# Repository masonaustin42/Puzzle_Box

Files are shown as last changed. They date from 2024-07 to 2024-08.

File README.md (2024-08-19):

# Puzzle Box

This puzzle box was created for my brother's bachelor party. The box displays a basic map on the LEDs on top, using a Teensy 4.1 microcontroller and an Arduino-compatible GPS receiver. 
The map updates in real-time, and helped navigate to different challenges that my brother had to complete to earn the codes to each of the different locks on the side of the box. The box cannot open until all 8 locks have been removed.
This project took about a month to develop, and it was made entirely from scratch aside from using some Arduino libraries to control the LEDs and interface with the GPS unit.

## Materials Used
- [Teensy 4.1](https://www.pjrc.com/store/teensy41.html)
- [NEO-6M GPS Receiver](https://a.co/d/7m8FWfx)
- [WS2812B Individually Addressable LED Rings](https://a.co/d/0RZDFQk)
- 4x [Brinks Luggage Padlock (2-Pack)](https://www.walmart.com/ip/Brinks-1-4in-32mm-3-Dial-Resettable-TSA-Luggage-Padlock-with-a-Steel-Cable-Shackle-2-Pack/5020233202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)
- All of the 3D Printed parts were in [Bambu Labs PLA Matte](https://us.store.bambulab.com/collections/bambu-lab-3d-printer-filament/products/pla-matte-filament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)

## Video Demo

https://github.com/user-attachments/assets/07382008-efad-4c62-b222-95e3310d10c2

## Example Usage

1. First, the device is powered on. Since the power switch is on the inside, this needs to be done before the locks are reinstalled.

2. Eight locks are installed on the exterior of the box, keeping it closed.

3. The GPS unit will look for a GPS signal. While the GPS is searching, the LEDs display a sweeping animation.

4. The map will update with the GPS data, showing the user's location in the center and a single point for the first objective the user must navigate to. For example, if the user was located in Seattle, WA and the first point was in San Francisco, CA the map would show the next point at the bottom of the display, indicating that the user needs to travel south.

5. The user then navigates to the point using the map. The map will continue to update as the user's location changes, displaying the relative location of the current objective, and getting closer to the center as the user approaches the destination.

6. Once the user successfully navigates to the objective, the LEDs will display a pulsing animation indicating that the user has arrived. This animation will last 3 minutes before updating again. This gives the user time to complete a task to find a code for a lock.

7. The display will then show the next objective. The user must repeat steps 4-6 for each objective.

8. Once the last objective is reached, a final rainbow animation will play indefinitely, indicating there are no more objectives to find. The locks may be removed from the puzzle box and the device can be shut down.

## Features

- Live location updates
- Custom animations
- Customizable amount of locations
- Battery Powered

## Technology Used

 





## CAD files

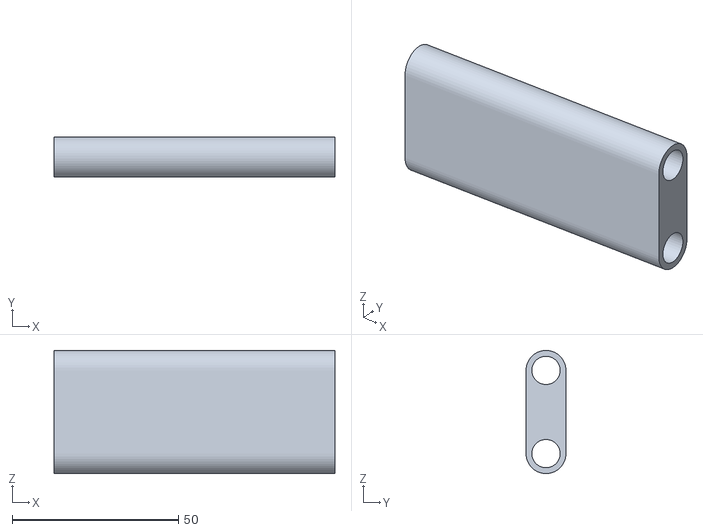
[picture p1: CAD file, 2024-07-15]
STLs/puzzle_box_hinge.stl
84.4 x 12.0 x 37.0

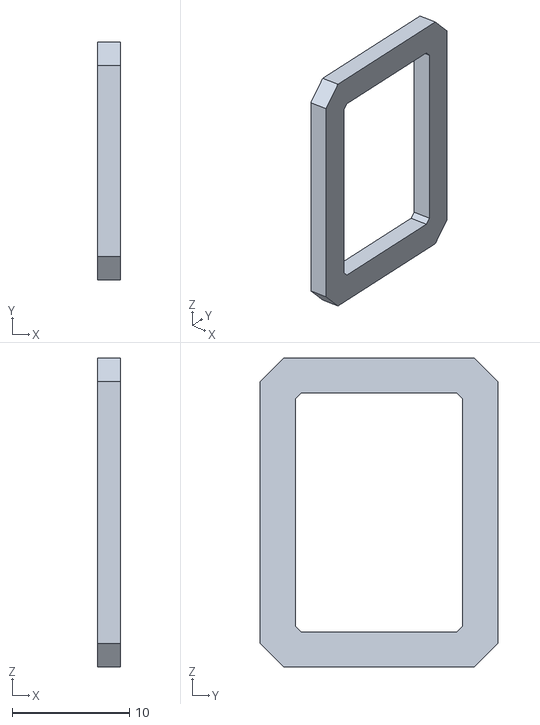
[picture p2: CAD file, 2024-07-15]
STLs/puzzle_box_clip.stl
2.00 x 20.3 x 26.4

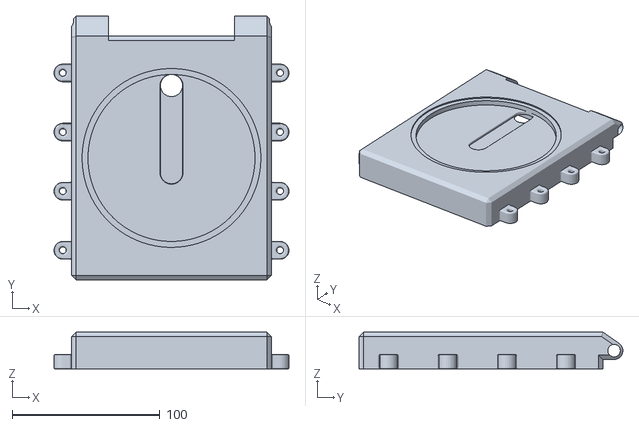
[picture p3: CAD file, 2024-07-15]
STLs/puzzle_box_lid.stl
159.0 x 178.5 x 24.8

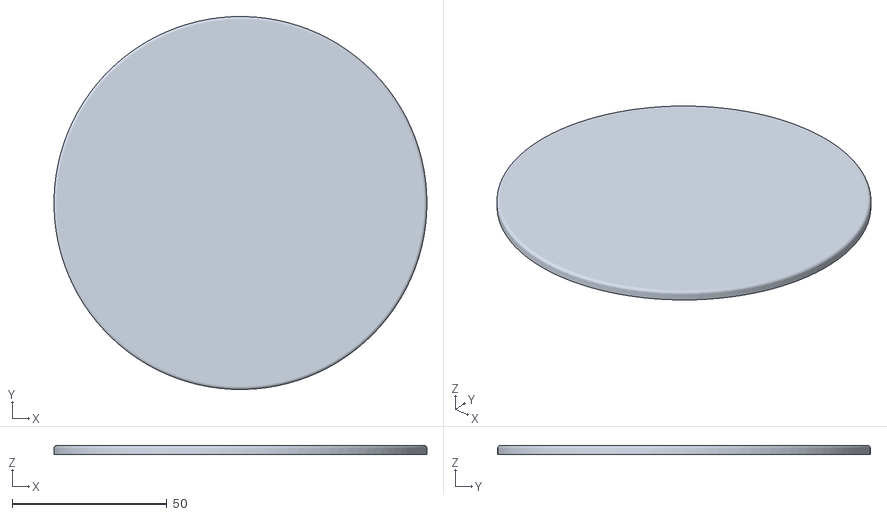
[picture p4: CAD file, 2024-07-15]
STLs/puzzle_box_diffuser.stl
120.6 x 120.6 x 3.00

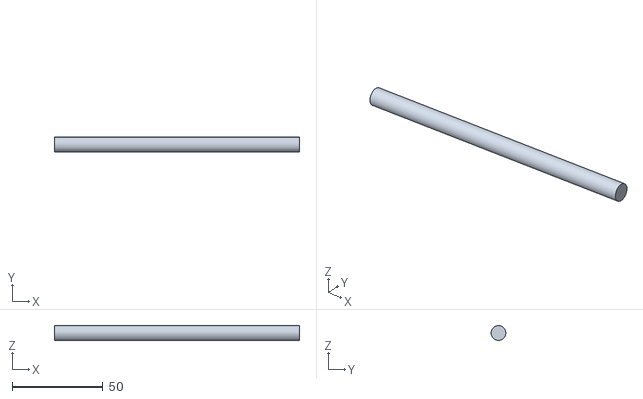
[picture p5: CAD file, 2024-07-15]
STLs/puzzle_box_pin.stl
135.0 x 8.13 x 8.14

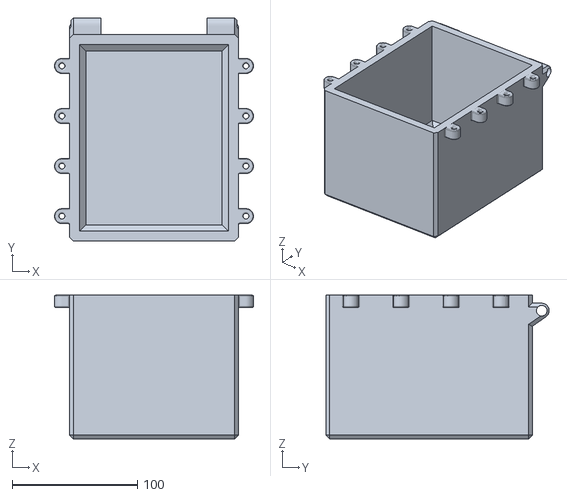
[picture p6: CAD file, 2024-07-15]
STLs/puzzle_box_base.stl
159.0 x 178.5 x 115.0

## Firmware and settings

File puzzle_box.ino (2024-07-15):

#include <WS2812Serial.h>
#define USE_WS2812SERIAL
#include <FastLED.h>           // include FastLED Library
#include <TinyGPSPlus.h>       // include GPS Data parsing library
// #include <SoftwareSerial.h>
#include <Wire.h>
#include <math.h>

// GLOBALS

// Uncomment to enable serial print statements
#define DEBUG

// Define GPS Points
const double Points[][2] = {
                            // { 47.542046203062654, -122.54614416764574} // hal's parents
                            // { 47.46740713249172, -122.61465463015585}  // home
                            // { 47.5424255792486, -122.6373545951069 },  // Merc
                            // { 47.53358012994527, -122.60760145751593}, // Taco Bell
                            // { 47.5166091859565, -122.62829766716061},  // Walmart
                            // { 47.50396635151055, -122.65078295913231}, // SC
                            { 47.50369865428797, -122.62911951854471},    // Fred Meyers
                            { 47.55570665517761, -122.54354641428509},    //manchester
                            { 47.565382834821264, -122.64965353307728},    //insight
                            { 47.66473591230466, -122.69514208676632},    //trappers
                            { 47.476690187351664, -122.5491264948875},    //banner forest
                            { 47.422176222346536, -122.54161606046057 },  // OBM
                            { 47.43409098724879, -122.54497605607479},    // Mom & Dad's
                            }; 
const int numPoints = 7;
int PointHues[] = {192, 64, 96, 160, 32, 210, 0};
uint8_t hue = 0;
int objective = 0;
int timeAtObjective = 0;
bool timeIsCounting = false;

const int objectiveTimeout = 180;

const int GPS_Baud = 9600;
// Instantiate TinyGPS+ object
TinyGPSPlus gps;

#define GPS Serial5

double bearing = 0;
double distance = 100.0;


// Instantiate LED Rings
const int NUM_LEDS = 93;
const int LED_PIN = 35;

CRGB leds[NUM_LEDS];

const int Rings[][2] = {{0, 31},
                          {32, 55},
                          {56, 71},
                          {72, 83},
                          {84, 91}};
const int RingSizes[] = {32, 24, 16, 12, 8, 1};
const int Ring6 = 92;

// declare function prototypes
void ledPoints();
void ledPulsing();
void ledSearching();
void debugPrint();
void debugPrintln();

void setup() {
  // put your setup code here, to run once:
  #ifdef DEBUG
  Serial.begin(9600);
  #endif

  GPS.begin(GPS_Baud);

  FastLED.addLeds<WS2812SERIAL, LED_PIN, BRG>(leds, NUM_LEDS);
  FastLED.setBrightness(75);
  // FastLED.setDither(0);

}

void loop() {
  // read GPS data
  while (GPS.available() > 0) {
    gps.encode(GPS.read());
  }
  // if received valid location data from GPS
  if (gps.location.isValid()) {
    // check distance between Objective and self
      distance = TinyGPSPlus::distanceBetween(
      gps.location.lat(),    // current lat/lng
      gps.location.lng(),
      Points[objective][0],  // objective lat/lng
      Points[objective][1]
    ) / 1000.0;
  }

  // Calculate bearings of each Objective
  bearing = calculateBearing(gps.location.lat(), gps.location.lng(), Points[objective][0], Points[objective][1]);

  // update global hue value 
  EVERY_N_MILLISECONDS(75) {
    hue += 10;
  }

  // check how long we've been at currently selected obj to select next one after 180 seconds
  EVERY_N_SECONDS(1) {
    debugPrint("Time at current Objective: ");
    // debugPrintln(timeAtObjective);
    if (timeAtObjective > 0 && timeAtObjective < objectiveTimeout) {
      timeAtObjective += 1;
    } else if (timeAtObjective == objectiveTimeout) {
      timeAtObjective += 1;
      objective += 1;
      timeIsCounting = false;
    } else {
      timeAtObjective = 0;
    }
  }

  // Draw the map
  drawMap(distance, bearing);
}

// Function to draw the map based off of:
// - Distance between self and current objective
// - Bearing to objective
void drawMap(double distance, double bearing) {
  #ifdef DEBUG
  displayGPSInfo();
  #endif

    debugPrint("objective num: ");
    debugPrintln(objective);
    debugPrint("Time at Objective: ");
    debugPrintln(timeAtObjective);
  if (objective >= numPoints) {
    ledRainbow();
  } else {
    debugPrint("Objective Status: ");
    if (! gps.location.isValid()) {
      debugPrint("GPS Searching    ");
      ledSearching();
    } else if (distance < 0.1) {
      debugPrint("Close to point    ");
      ledPulsing();
      // set timeIsCounting to true when entering the space
      // debugPrintln(timeAtObjective);
      if (!timeIsCounting && timeAtObjective == 0) {
        timeIsCounting = true;
        timeAtObjective = 1;
        };
    } else {
      debugPrint("Displaying points    ");
      ledPoints();
      debugPrint("Bearing: ");
      // debugPrintln(bearing);
      debugPrint("Distance: ");
      // debugPrintln(distance);
    }
    debugPrintln("");
  }
  
  FastLED.show();
}

// Function to convert degrees to radians
double degreesToRadians(double degrees) {
  return degrees * (PI / 180.0);
}

// Function to calculate the bearing from current location to target location
double calculateBearing(double lat1, double lon1, double lat2, double lon2) {
  // Convert latitude and longitude from degrees to radians
  lat1 = degreesToRadians(lat1);
  lon1 = degreesToRadians(lon1);
  lat2 = degreesToRadians(lat2);
  lon2 = degreesToRadians(lon2);
  
  // Calculate the difference in longitudes
  double deltaLon = lon2 - lon1;

  // Calculate the components of the bearing
  double y = sin(deltaLon) * cos(lat2);
  double x = cos(lat1) * sin(lat2) - sin(lat1) * cos(lat2) * cos(deltaLon);
  
  // Calculate the initial bearing in radians
  double initialBearing = atan2(y, x);

  // Convert the bearing from radians to degrees
  double bearing = initialBearing * (180.0 / PI);

  // Normalize the bearing to a 0-360 range
  bearing = fmod((bearing + 360.0), 360.0);

  return bearing;
}

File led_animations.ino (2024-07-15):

void ledPulsing() {
  // uint8_t tempHue = hue;

  uint8_t i = map(beat8(60, 0), 0, 255, 20, 0);
  if (i == 5) {
    leds[92] = CHSV(PointHues[objective], 200, 255);
  } else if (i < 5) {
    for (int j = Rings[i][0]; j <= Rings[i][1]; j++) {
      leds[j] = CHSV(PointHues[objective], 200, 255);
    }
  }
  fadeToBlackBy(leds, NUM_LEDS, 10);
}



void ledSearching() {
  uint8_t speed = beat8(30, 0);
  uint8_t ring1 = map(speed, 0, 255, Rings[0][0], Rings[0][1]);
  uint8_t ring2 = map(speed, 0, 255, Rings[1][0], Rings[1][1]);
  uint8_t ring3 = map(speed, 0, 255, Rings[2][0], Rings[2][1]);
  uint8_t ring4 = map(speed, 0, 255, Rings[3][0], Rings[3][1]);
  uint8_t ring5 = map(speed, 0, 255, Rings[4][0], Rings[4][1]);

  leds[ring1] = CHSV(85, speed, 255);
  leds[ring2] = CHSV(85, speed, 255);
  leds[ring3] = CHSV(85, speed, 255);
  leds[ring4] = CHSV(85, speed, 255);
  leds[ring5] = CHSV(85, speed, 255);
  leds[92] = CHSV(85, speed, 255);

  fadeToBlackBy(leds, NUM_LEDS, 3);
}

 

void ledPoints() {
  FastLED.clear();

  int selectedRing = 0;
  if (distance > 0.1 && distance <= 1) {
    selectedRing = 4;
  } else if (distance > 1 && distance <= 2) {
    selectedRing = 3;
  } else if (distance > 2 && distance <= 3) {
    selectedRing = 2;
  } else if (distance > 3 && distance <= 4) {
    selectedRing = 1;
  } else {
    selectedRing = 0;
  }

    int offset = 0;
    for (int i = 0; i < selectedRing; i++) {
      offset += RingSizes[i];
    }

    int pointLed = ((bearing / 360) * RingSizes[selectedRing]) + offset;
    leds[pointLed].setHue(PointHues[objective]);
    leds[92].setHue(hue);
}

void ledRainbow() {
  for (int ring = 0; ring <= 4; ring++) {
    for (int i = Rings[ring][0]; i <= Rings[ring][1]; i++) {
      uint8_t wave = (255 / (Rings[ring][1] - Rings[ring][0] + 1)) * (Rings[ring][1] - i);
      leds[i].setHue(hue + wave);
    }
  }
  leds[92].setHue(hue);
}

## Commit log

2024-05-24 add helper function to calculate distance and bearing of objectives
2024-05-26 add GPS test and add compass code to puzzle_box.ino, need to calibrate compass
2024-05-26 update wiring diagram
2024-06-22 finish base program
    [output.csv]
2024-06-23 add debug print statements and changed mp3 player to triggers instead of serial control
2024-07-15 remove unnecessary files and finalize code
    [output.csv]
2024-07-15 add puzzle box stl files
    [puzzle_box_base.stl, puzzle_box_clip.stl, puzzle_box_diffuser.stl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]
2024-07-24 Add materials and video to README
